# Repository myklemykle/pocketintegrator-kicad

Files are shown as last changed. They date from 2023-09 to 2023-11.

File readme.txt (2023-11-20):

LICENSE STATEMENT:

The hardware design in this repo is released under the GNU GPL Version 3.0 (and later).
The documentation is released under the Creative Commons Attribution Share Alike 4.0 International license.
These liceneses, and other licenses for third-party symbols, footprints and models included in this repo,
can be found under /library/licenses .

DESCRIPTION:

Pocket Integrator v11 (PI) is an add-on board for Pocket Operator (PO) series of 
handheld drum/rhythm instruments made by Teenage Engineering SA.  It hosts a
Raspberry Pi RP2040 mcu, a LSM6DSO-series accelerometer from STMicro, a 1.8v
QSPI-compatible flash memory chip in 8-pin SOIC format (such as a Winbond W25Q128JW),
a few power supply/buffer ICs, four tactile switches, and misc SMD passives and connectors.

This PI board fits snugly to the back of any model of PO, but must be held in place
with two rubber bands.  I recommend a pair of neoprene O-rings, size 027, 70 durometer.

Four GPIO pin connections are made through anti-aliasing audio-pass filters to 
a pair of 3.5mm TRS connectors. These can be used either for PWM audio output
or analog audio input.

PI can draw power either from the PO batteries when attached to the PO, 
or from the USB-C port when connected to a suitable USB-C host.
When attached to USB power, PI can supply current back to the attached
PO, allowing it to run without batteries installed.

Pin connections are made from RP2040 GPIO pins to the SWD pins of the PO, 
allowing PI to be used as a debugger and reprogrammer for POs.  
The PO Play LED is also connected to GPIO, so the PI can know if the PO is playing.  

All these pin connections are made between a pogo-pin block on the PI 
and 12 programming/debug pads on the back of every PO. 
The 6x2 grid of pogo pin connectors should have these measurements:

	.100" (2,540mm) Pitch
	.055" (1,397mm) Stroke
	.236" (5,994mm) Initial Height

Compatible 6x2 pogo pin blocks are available from Mill-Max and Preci-Dip. 
Other pogo pin options may exist by combining smaller block arrangements.
(If necessary, a 5x2 block of pins can be used, 
as the sixth column consists only of redundant ground connections.)

FILES:

integrator.*, integrator-cache.*: 
	KiCad project files.
	NOTE: Pocket Integrator was designed with KiCad version 5, 
	and has not been tested with later versions. 

gerber/: 
	exported gerber files for fabrication.

library/: 
	models, symbols and footprints used by KiCad.

pins.h: 
	Documenation of RP2040 pin connections to the rest of the board.

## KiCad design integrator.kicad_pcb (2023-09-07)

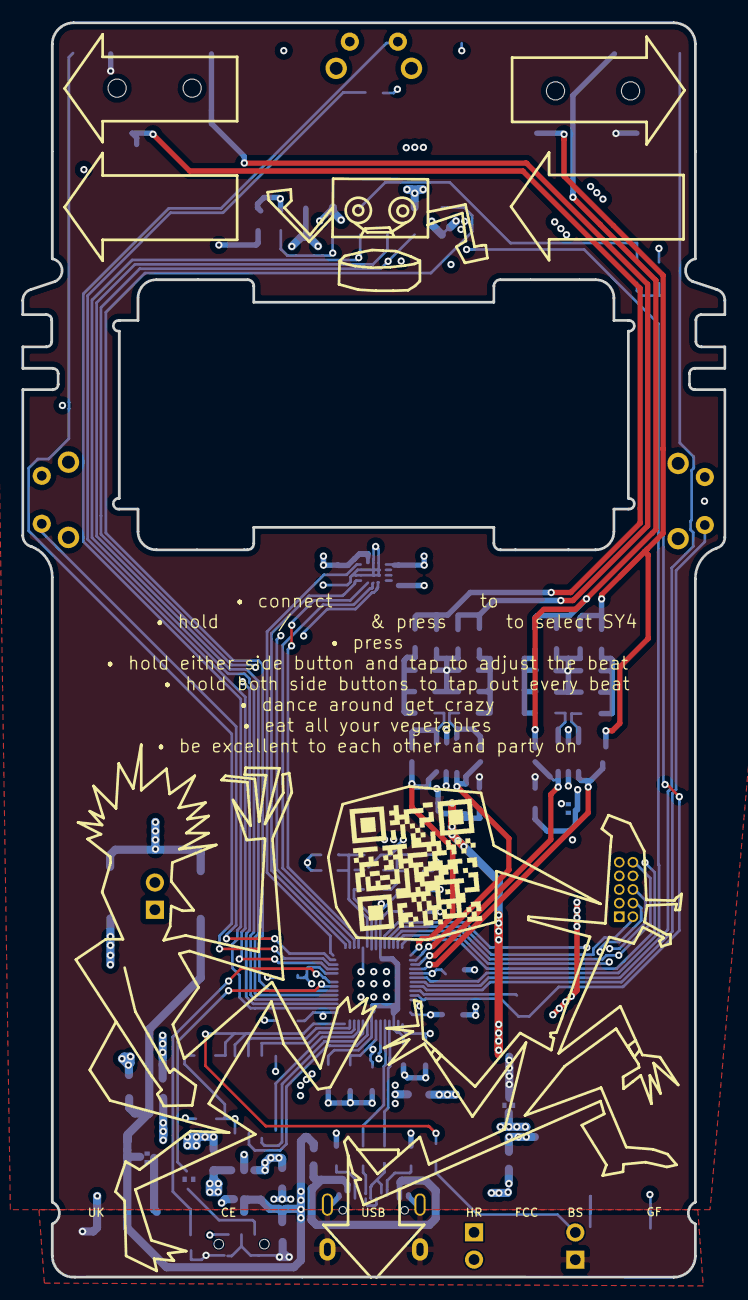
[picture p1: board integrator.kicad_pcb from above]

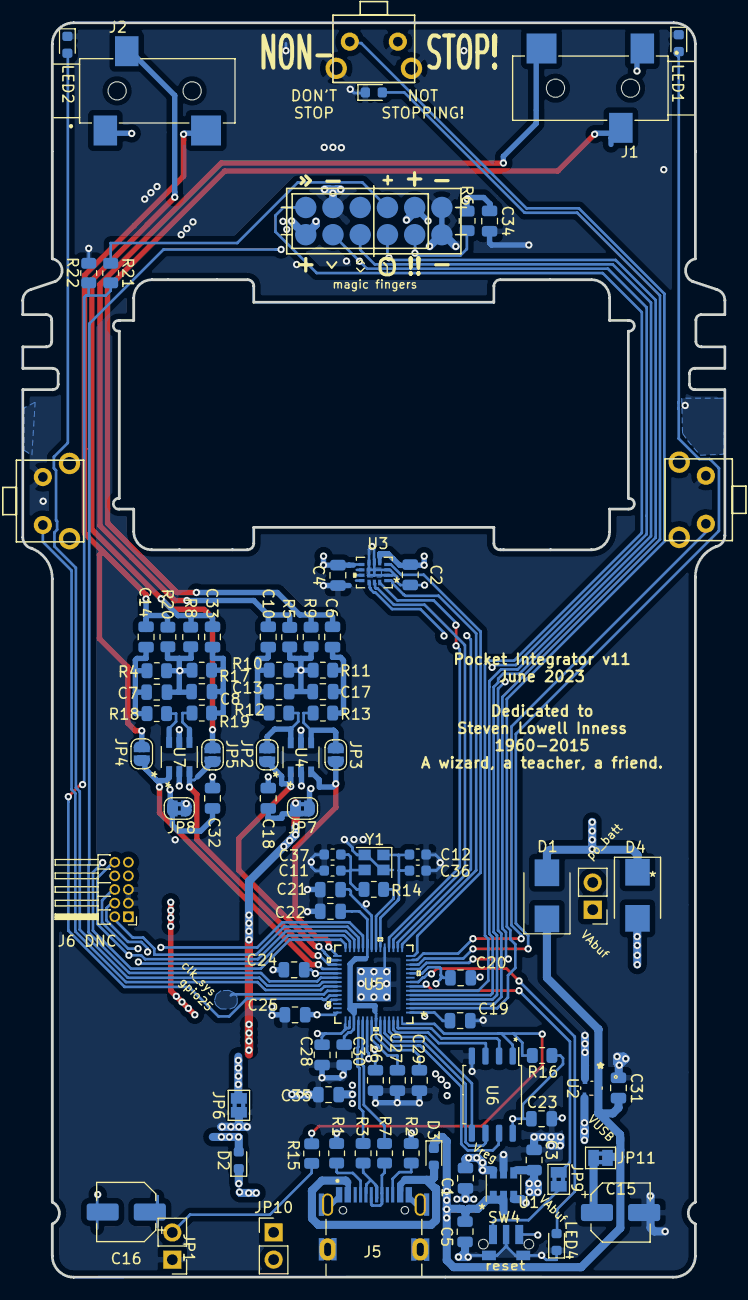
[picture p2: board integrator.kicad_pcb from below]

Board: 4 copper layers, 65.5 x 117.0 mm, 95 parts (95 on the bottom side), 72 nets.

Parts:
C1, C3, C5: 1uf ceramic; C_0805_2012Metric
C2, C4, C18, C19, C20, C21, C22, C23, C24, C25, C26, C27, C29, C32, C34, C35: 0.1uf; C_0805_2012Metric
C6, C10, C14, C33: 47uf; C_0805_2012Metric
C7, C8, C13, C17: 0.1uf 5%; C_0805_2012Metric
C11, C12: 6pf; C_0603_1608Metric
C15, C16: 100uf; CP_Elec_5x4.4
C28, C30: 1uf; C_0805_2012Metric
C31: 0.1uf ceramic; C_0805_2012Metric
C36, C37: TBD/DNC; C_0603_1608Metric
D1: <100mv drop; D_SMB
D2: shottky; D_0603_1608Metric
D3: 450mv drop; D_0603_1608Metric
D4: 200mv drop; D_SMB
J1, J2: SJ-3523-SMT; CUI_SJ-3523-SMT-TR
J5: USB4105-GF-A; HRO_TYPE-C-31-M-12-Paste-Lugs
J6 DNC: Conn_ARM_JTAG_SWD_10; PinHeader_2x05_P1.27mm_Horizontal
J7: test point; PinHeader_1x02_P2.54mm_Vertical
JP1: Jumper_NO_Small; PinHeader_1x02_P2.54mm_Vertical
JP2, JP3, JP4, JP5: Jumper_NO_Small; SolderJumper-2_P1.3mm_Open_RoundedPad1.0x1.5mm
JP6, JP9, JP11: Jumper; SolderJumper-2_P1.3mm_Bridged2Bar_Pad1.0x1.5mm
JP7, JP8: Jumper_NC_Small; SolderJumper-2_P1.3mm_Bridged2Bar_RoundedPad1.0x1.5mm
JP10: Jumper; PinHeader_1x02_P2.54mm_Vertical
LED1, LED2, LED3, LED4: CSL1901VW1; LED_0603_1608Metric
POGO1: PO pogos; 813-22-012-30-004101-millmax-pogopins-2x6
R1, R2, R6: 5.1k; R_0805_2012Metric
R3, R7: 27 5%; R_0805_2012Metric
R4, R10, R11, R17: 100 1%; R_0805_2012Metric
R5, R8, R9, R20: 1.8K 1%; R_0805_2012Metric
R12, R13, R18, R19: 220 1%; R_0805_2012Metric
R14, R15: 1k 5%; R_0805_2012Metric
R16: 10k; R_0805_2012Metric
R21: 100k; R_0805_2012Metric
R22: 220k; R_0805_2012Metric
SW1, SW2, SW3: EVQP40B3M; TL1105VF100Q
SW4: 436333033816
U1: XC6415; SOT-23-6
U2: XC6501D331NR-G
U3: LSM6DSO32XTR
U4, U7: NL27WZ16DTT1G
U5: RP2040
U6: IS25WP128F-JBLE; SOIC-8_5.23x5.23mm_P1.27mm
Y1: Crystal; Crystal_SMD_2520-4Pin_2.5x2.0mm

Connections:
/PWM_L1: JP2.1, R12.2, U4.6
/PWM_L2: R18.2, U7.6
/PWM_LL1: C10.2, C13.1, R10.2, R12.1
/PWM_LL2: C7.1, C14.2, R4.2, R18.1
/PWM_R1: JP3.1, R13.2, U4.4
/PWM_R2: R19.2, U7.4
/PWM_RR1: C6.2, C17.1, R11.2, R13.1
/PWM_RR2: C8.1, C33.2, R17.2, R19.1
/po_batt: C34.1, D1.2, D4.1, J7.2, POGO1.4, POGO1.11, R6.1
/xin: C12.2, C36.2, U5.20, Y1.1
/xout: R14.1, U5.21
AGnd: C7.2, C8.2, C13.2, C17.2, C18.2, C32.2, J1.1, J2.1, JP6.1, R4.1, R5.1, R8.1, R9.1, R10.1, R11.1, R17.1, R20.1
Aref_enable: U1.3, U5.39
Earth: C1.1, C2.2, C3.2, C4.2, C5.1, C11.2, C12.1, C15.2, C19.2, C20.2, C21.2, C22.2, C23.2, C24.2, C25.2, C26.2, C27.2, C28.1, C29.2, C30.1, C31.2, C34.2, C35.2, C36.1, C37.2, J5.S1, J5.S2, J5.S3, J5.S4, J6 DNC.3, J6 DNC.5, JP1.1, JP6.2, LED1.1, LED2.1, LED3.1, LED4.1, POGO1.1, POGO1.2, POGO1.10, R1.2, R2.1, R22.1, SW1.2, SW1.3, SW1.4, SW2.1, SW2.3, SW2.4, SW3.1, SW3.3, SW3.4, SW4.2, SW4.mp1, SW4.mp2, U1.5, U2.2, U3.2, U3.3, U3.6, U3.7, U4.2, U5.19, U5.57, U6.4, U7.2
unnamed: C11.1, C37.1, R14.2, Y1.3
unnamed: C15.1, JP11.2
unnamed: C18.1, JP7.1, U4.5
unnamed: C32.1, JP8.2, U7.5
unnamed: D2.2, J6 DNC.7
unnamed: J5.A5, R1.1
unnamed: J5.A6, J5.B6, R7.1
unnamed: J5.A7, J5.B7, R3.2
unnamed: J5.B5, R2.2
unnamed: JP1.2, R15.2
unnamed: JP9.2, SW4.1
unnamed: JP10.2, SW4.3
unnamed: POGO1.6, R21.2
unnamed: R15.1, R16.1, U5.56, U6.1
unnamed: U5.51, U6.7
unnamed: U5.52, U6.6
unnamed: U5.53, U6.5
unnamed: U5.54, U6.3
unnamed: U5.55, U6.2
VAbuf: C3.1, D4.2, J7.1, JP7.2, JP8.1, U1.4
VInt: C22.1, C29.1, C30.2, U5.23, U5.45, U5.50
VRaw: C5.2, C31.1, D1.1, D2.1, D3.1, JP11.1, U1.1, U1.2, U2.1, U2.4
VReg: C1.2, C2.1, C4.1, C19.1, C20.1, C21.1, C23.1, C24.1, C25.1, C26.1, C27.1, C28.2, R16.2, U1.6, U3.5, U3.8, U5.1, U5.10, U5.22, U5.33, U5.42, U5.43, U5.44, U5.49, U6.8
VUSB: C35.1, U2.3, U5.48
imu_int: U3.4, U5.14
led1: LED1.2, U5.12
led2: LED2.2, U5.35
led3: LED3.2, U5.11
led4: LED4.2, U5.8
pi_reset: J6 DNC.10, JP10.1, U5.26
pi_swclk: J6 DNC.4, U5.24
pi_swdio: J6 DNC.2, U5.25
pi_swo: J6 DNC.6, U5.27
pi_txin: J6 DNC.8, U5.28
po_play: POGO1.12, U5.6
po_reset: POGO1.3, R6.2, U5.34
po_swclk: POGO1.5, U5.4
po_swdio: POGO1.7, U5.5
po_swo: POGO1.9, U5.3
po_wake: R21.1, R22.2, U5.38
ring1: JP3.2, U4.3, U5.29
ring1_out: C6.1, J1.3, R9.2
ring2: JP5.1, U5.31, U7.3
ring2_out: C33.1, J2.3, JP5.2, R8.2
spi_clock: U3.13, U5.17
spi_cs: U3.12, U5.16
spi_miso: U3.1, U5.15
spi_mosi: U3.14, U5.18
sw1: SW1.1, U5.13
sw2: SW2.2, U5.36
sw3: SW3.2, U5.2
sw4: JP9.1, U5.7
tip1: JP2.2, U4.1, U5.30
tip1_out: C10.1, J1.2, R5.2
tip2: JP4.1, U5.32, U7.1
tip2_out: C14.1, J2.2, JP4.2, R20.2
usb_d+: R7.2, U5.47
usb_d-: R3.1, U5.46

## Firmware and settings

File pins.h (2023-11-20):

#ifndef __PINS_H
#define __PINS_H

// Pins:
const int button1Pin = 10;   // sw1 = gpio10
const int button2Pin = 24;   // sw2 = gpio24
const int button3Pin = 0;   // sw3/nonstop
const int button4Pin = 5;   // sw4/reset
const int led1Pin =  9;    // pwm channel 4B
const int led2Pin =  23;    // pwm channel 3B
const int led3Pin = 8; // pwm channel 4A
const int nonstopLedPin = led3Pin; 
const int led4Pin = 6;	// pwm channel 3A
const int boardLedPin = led4Pin;
const int tip1 = 19; 	// pwm channel 1B
const int tip2 = 21; 		// pwm channel 2B
const int ring1 = 18; // pwm channel 1A
const int ring2 = 20;	// pwm channel 2A
const int outPins[4] = { tip1, ring1, tip2, ring2 };
const int PO_play = 4; 		// goes high on PO play (runs to play LED)
const int PO_wake = 26;			// goes low when PO sleeps -- gpio26/adc0
const int PO_reset = 22;			
const int PO_SWCLK = 2;			// jtag/stlink pins:
const int PO_SWDIO = 3;
const int PO_SWO   = 1;
const int IMU_int = 11;
const int SPI_clock = 14;
const int SPI_cs = 13;
const int SPI_miso = 12;
const int SPI_mosi = 15;
// drive Aref_enable high to enable 2.5v audio power supply
const int Aref_enable = 27; 
// Unused pins must be tied high or low, or else the whole CMOS chip can glitch.
const int unusedPins[6] = { 7,16,17,25,28,29 };
// These are normally unused, but used in testing/debug:
// a UART for picoprobe or misc future handiness, goes to JTAG pins
const int PI_swo = 16; // UART0 TX
const int PI_txin = 17; // UART0 RX
// For testing/tuning crystal, RP2040 can send clk_sys direct to this pin:
const int PI_clk_sys = 25;

#endif // PINS_H 

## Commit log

2021-03-13 saved before library tweak
    [integrator.sch]
2021-03-22 snapshot everything for safety
    [ICM-20600--3DModel-STEP-56544.STEP, ICM-20600.step, TL1105VFxxxx.stp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]
2021-03-26 snapshot with hackzone
    [integrator.kicad_pcb, integrator.sch]
2021-03-26 bye bye hackzone
    [integrator.kicad_pcb]
2021-06-22 last changes of rev3
    [integrator-B_Mask.gbr, integrator-B_Paste.gbr, integrator-B_SilkS.gbr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]
2021-07-06 evt4 schem w/o rocker switches
    [ICM-42605.step, integrator.sch]
2021-07-06 5x2 pogo
    [integrator.sch]
2021-07-10 evt4 pcb layout
    [integrator.kicad_pcb, integrator.sch]
2021-07-11 even more final evt4
    [integrator.kicad_pcb]
2021-07-12 evt4 submitted to oshpark
    [integrator.kicad_pcb]
2021-08-11 moved po_wake to analog pin 14 +tweaks
    [integrator.kicad_pcb, integrator.sch]
2022-04-09 tighter slot, narrower kickstand
    [integrator.kicad_pcb]
2022-04-23 breakout tab
    [CUI_DEVICES_SP-3533-02.step, integrator.kicad_pcb]
2022-04-23 gerbers to jblpcb
    [integrator-B_Mask.gbr, integrator-B_Paste.gbr, integrator-B_SilkS.gbr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]
2022-05-07 version 5 schematic complete
    [LGA_O32XTR_STM.step, Microchip_-_TC1263-3.3VOATR.step, integrator.sch]
2022-05-09 libs & models
    [2171750001.stp, TL1105VFxxxx.stp, TSX-3225.step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]
2022-05-09 rev5 pcb checkpoint (close)
    [integrator.kicad_pcb, integrator.sch]
2022-05-19 v5 sent to fab
    [CUI_DEVICES_SJ-3524-SMT-TR.step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]
2022-05-19 cleanup unused stuff
    [integrator-jlcpcb.csv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]
2022-09-13 tweaks/fixes to v5
    [integrator.kicad_pcb, integrator.sch]
2022-09-13 v5 gerbers as sent to pcbway
    [integrator-B_Mask.gbr, integrator-B_Paste.gbr, integrator-B_SilkS.gbr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]
2022-09-13 major cleanup/reorg of symbols and footprints
    [integrator-2021-01-18-19-47-36.sch, integrator.sch]
2022-09-13 clean/reorg models, dcm files, dir-splat
    [integrator.kicad_pcb]
2022-09-15 WIP before schematic append
    [integrator.sch]
2022-09-16 v6 schematic complete
    [integrator.sch]
2022-09-19 lib/footprint tweaks/fixes for pcbnew
    [integrator.sch]
2022-09-19 schematic tweaks/fixes
    [integrator.sch]
2022-09-20 WIP routing pcb
    [integrator.kicad_pcb, integrator.sch]
2022-09-20 WIP mostly placed
    [integrator.kicad_pcb, integrator.sch]
2022-09-20 WIP before tidying/tweaking btm layer
    [integrator.kicad_pcb, integrator.sch]
2022-09-20 WIP all traces laid
    [integrator.kicad_pcb, integrator.sch]
2022-09-21 fixed dup values
    [integrator.sch]
2022-09-21 passed DRC
    [integrator.kicad_pcb]
2022-09-21 added xtal model
    [integrator.kicad_pcb]
2022-09-21 removed bridge plug
    [integrator.kicad_pcb]
2022-09-22 completed front artwork
    [integrator.kicad_pcb]
2022-09-22 tweaked kickstand slots
    [integrator.kicad_pcb]
2022-09-23 corrected gerbers sent to fab
    [integrator-B_Mask.gbr, integrator-B_Paste.gbr, integrator-B_SilkS.gbr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]
2022-10-08 tweaks & fixes
    [integrator.kicad_pcb, integrator.sch]
2022-10-08 slot tweaks
    [integrator.kicad_pcb]
2022-10-10 bugfixes on v6
    [integrator.kicad_pcb, integrator.sch]
2022-11-09 v7 gerbers sent to jlc
    [integrator-B_Mask.gbr, integrator-B_Paste.gbr, integrator-B_SilkS.gbr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]
2022-11-09 adj popcorn spacing
    [integrator.kicad_pcb]
2022-12-10 changing to ABM10-166-12.000MHZ-T3 crystal
    [integrator.kicad_pcb, integrator.sch]
2022-12-10 repositioned audio output stage
    [integrator.kicad_pcb]
2023-01-03 adjusted jack positions, added back jumper
    [integrator.kicad_pcb]
2023-01-08 widened edges to 60mm, re-added jumper
    [integrator.kicad_pcb, integrator.sch]
2023-01-11 v8 schematic & pcb
    [integrator.kicad_pcb, integrator.sch]
2023-01-11 reorg po debug pins
    [integrator.kicad_pcb, integrator.sch]
2023-01-12 test points & tweaks
    [integrator.kicad_pcb, integrator.sch]
2023-01-12 moved logos, misc tweaks
    [integrator.kicad_pcb, integrator.sch]
2023-01-13 resistor tweaks
    [integrator.sch]
2023-01-13 v8 gerbers as sent
    [integrator-B_Mask.gbr, integrator-B_Paste.gbr, integrator-B_SilkS.gbr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]
2023-02-21 v9 checkpoint/wip
    [integrator.kicad_pcb, integrator.sch]
2023-02-21 v9 schematic updates
    [integrator.sch]
2023-02-21 v9 checkpoint 2
    [integrator.kicad_pcb, integrator.sch]
2023-02-21 v9 checkpoint 3
    [integrator.kicad_pcb, integrator.sch]
2023-02-22 possibly finished v9
    [integrator.kicad_pcb, integrator.sch]
2023-02-22 sysclk testpad, jmpr cleanup
    [integrator-B_Mask.gbr, integrator-B_Paste.gbr, integrator-B_SilkS.gbr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]
2023-02-22 hard reset jumper open
    [integrator-B_Mask.gbr, integrator-B_Paste.gbr, integrator-B_SilkS.gbr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]
2023-02-22 update D2 comment
    [integrator.sch]
2023-03-31 final v9 gerbers to jlcpcb
    [integrator-B_Mask.gbr, integrator-B_Paste.gbr, integrator-B_SilkS.gbr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]
2023-03-31 vreg to jtag pin 1
    [integrator.kicad_pcb, integrator.sch]
2023-04-04 jumper & capacitor tweaks
    [integrator.kicad_pcb, integrator.sch]
2023-04-11 qrcode & misc tweaks
    [integrator.kicad_pcb, integrator.sch]
2023-04-13 v10 submission #1
    [integrator-B_Mask.gbr, integrator-B_Paste.gbr, integrator-B_SilkS.gbr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]
2023-04-28 mod pogo1 footprint for 2x5 connector
    [integrator.kicad_pcb]
2023-04-30 10.1 gerbers sent to CCC for quote
    [integrator-B_Mask.gbr, integrator-B_Paste.gbr, integrator-B_SilkS.gbr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]
2023-04-30 clearer QRcode
    [integrator.kicad_pcb]
2023-07-07 larger instructions
    [integrator.kicad_pcb]
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2023-07-07 v11 sent to JLC 7/7/2023
    [integrator-B_Mask.gbr, integrator-B_Paste.gbr, integrator-B_SilkS.gbr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]
2023-09-07 added drill/place origin, remade gerbers
    [integrator-B_Mask.gbr, integrator-B_Paste.gbr, integrator-B_SilkS.gbr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]
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

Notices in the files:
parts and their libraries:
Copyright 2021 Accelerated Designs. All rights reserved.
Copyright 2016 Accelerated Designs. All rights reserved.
